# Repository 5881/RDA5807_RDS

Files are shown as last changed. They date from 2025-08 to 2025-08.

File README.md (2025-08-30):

# Радиоприёмник на RDA5807 с поддержкой RDS
Отображается название станций (блок 0A/0B), дата и время (блок 4A) и 
радиотекст (блок 2A). Использован микроконтроллер STM32F103C8T6 и TFT 
дисплей 128x128 на ST7735. Код написан на C с использованием библиотеки 
LibopenCM3. Отличается хорошей чувствительностью и очень приличным 
качеством звучания плюс кварцевая стабилизация.

# RDS-enabled RDA5807 radio
Shows the name of the stations (block 0A/0B), date and time (block 4A) 
and Radiotext (Block 2A). STM32F103C8T6 microcontroller and TFT 128x128 
display on ST7735 was used. The code is written in C using the 
LibopenCM3. It is characterized by good sensitivity and very decent 
sound quality plus quartz stabilization.

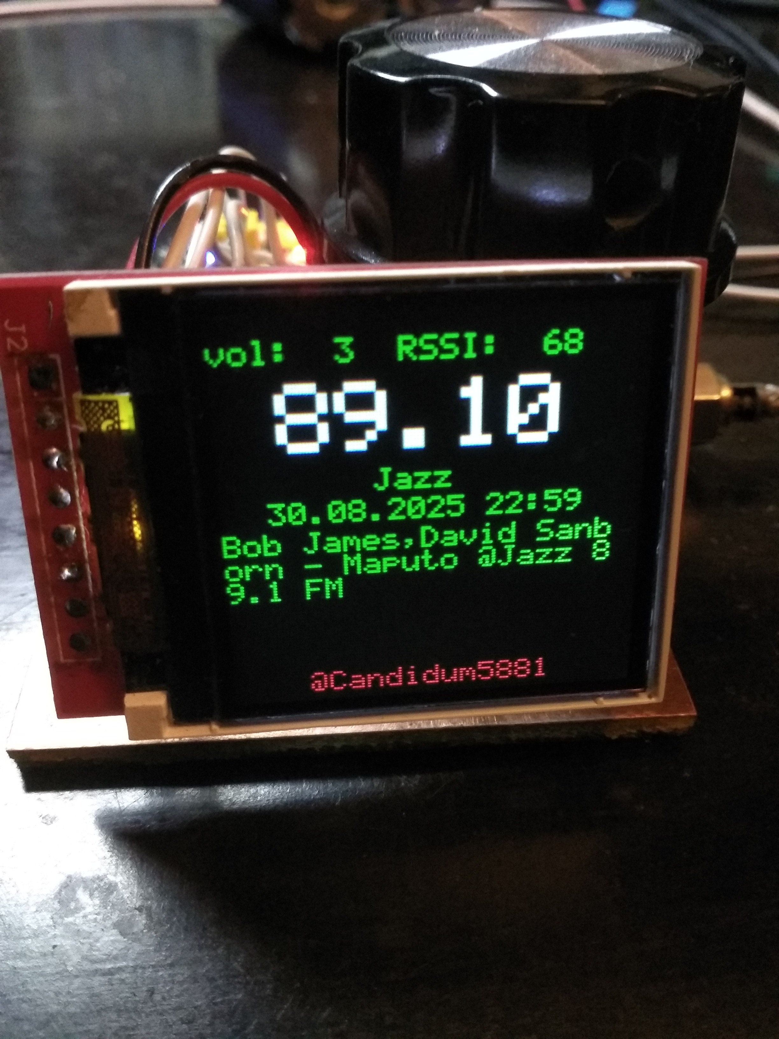
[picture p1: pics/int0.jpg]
Display


# Instructions
 
 1. $sudo pacman -S openocd arm-none-eabi-binutils arm-none-eabi-gcc arm-none-eabi-newlib arm-none-eabi-gdb
 2. $git clone https://github.com/5881/RDA5807_RDS.git
 3. $cd RDA5807_RDS
 4. $git submodule update --init # (Only needed once)
 5. $TARGETS=stm32/f1 make -C libopencm3 # (Only needed once)
 6. $make 
 7. $make flash

Александр Белый 2025

@candidum5881

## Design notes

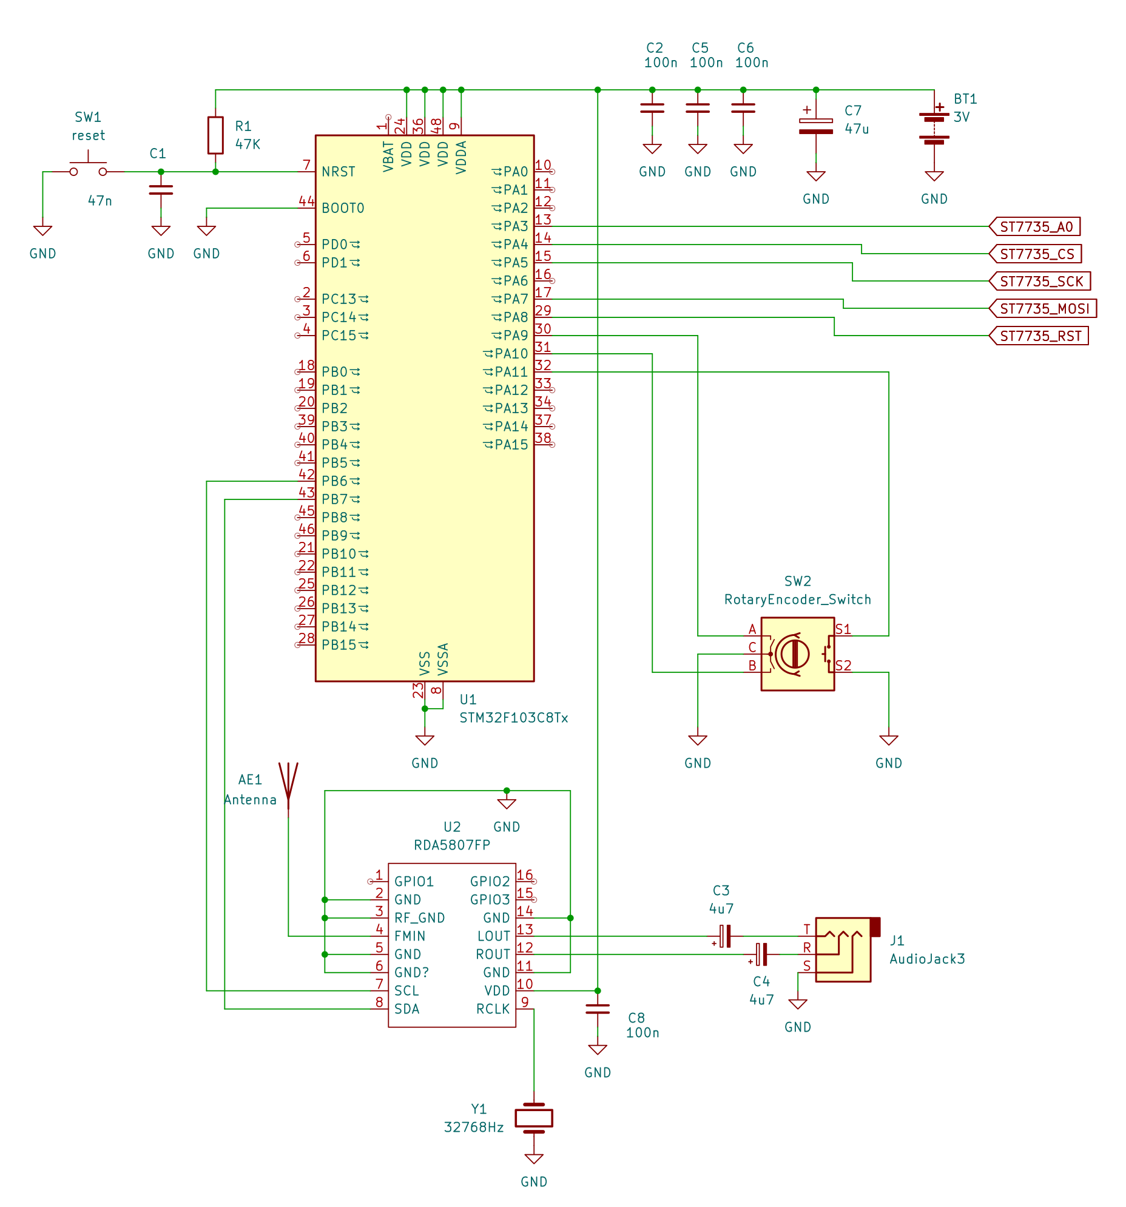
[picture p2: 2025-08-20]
schematic/rda5807.png

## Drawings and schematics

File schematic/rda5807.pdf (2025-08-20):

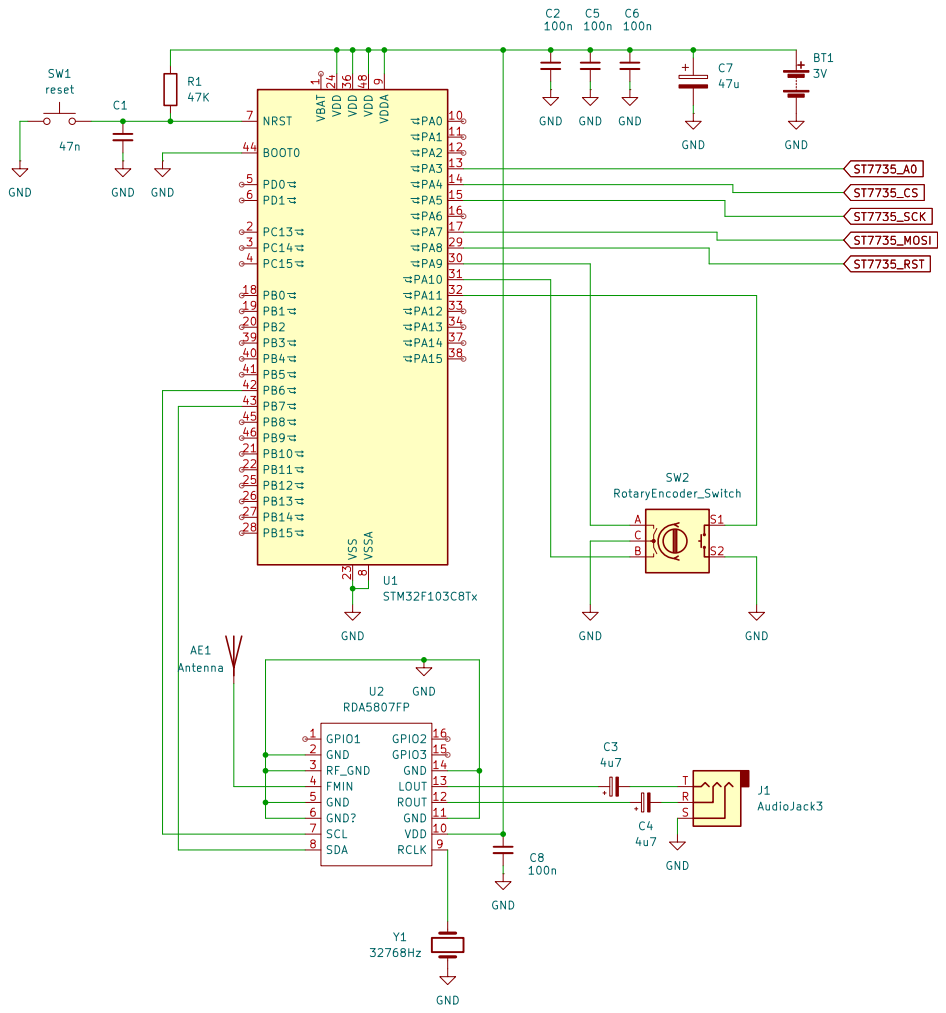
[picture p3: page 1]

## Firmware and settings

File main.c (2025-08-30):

/*
 * Приёмник RDA5807
 * v0.1 15 aug 2025
 * v0.9 20 aug 2025
 * v1.0 30 aug 2025
 * выкинул st_printf и заменил на stdio
 * Alexandr Belyy
 * /

/**********************************************************************
 * Секция include и defines
**********************************************************************/
#include <libopencm3/stm32/rcc.h>
//#include <libopencm3/stm32/timer.h>
#include <libopencm3/stm32/gpio.h>
//#include <libopencm3/stm32/adc.h>
#include <libopencm3/stm32/spi.h>
#include <libopencm3/stm32/exti.h>
#include <libopencm3/cm3/nvic.h>
#include "st7735_128x128.h"
#include "rda5807.h"
#include <libopencm3/stm32/i2c.h>
//#include "st_printf.h"
#include <stdio.h>
#include <string.h>
//#include "logo.h"

uint32_t freq=89100;
uint8_t vol=2;
uint8_t rssi;
uint8_t mode=1;

void change_setting(int cmd){
//static uint8_t encoder_mode=0;

/*mode
 * 1- freq
 * 0- vol
 *encoder mode
 * 0-change mode
 * 1-change set
 */
switch (cmd){
	case 1:
		if(mode) {if(freq<108000)freq+=100;} else {if(vol<15)vol+=1;}
		break;
	case -1:
		if(mode) {if(freq>76000)freq-=100;} else {if(vol>0)vol-=1;}
		break;
	case 0:
		mode=!mode;
		break;
	}
}

void applay_setting(){
	static uint32_t old_freq=87000;
	static uint8_t old_vol=0;
	if(freq!=old_freq){RDA5807_set_freq(freq); old_freq=freq;}
	if(vol!=old_vol){RDA5807_set_vol(vol); old_vol=vol;}
}

static void spi1_init(void){
	//spi1 - display
	/* Enable SPI1 Periph and gpio clocks */
	//rcc_periph_clock_enable(RCC_AFIO);
	rcc_periph_clock_enable(RCC_SPI1);
	rcc_periph_clock_enable(RCC_GPIOA);
	/* Configure GPIOs:
	 * SCK=PA5 
	 * DC=PA3
	 * MOSI=PA7 
	 * STCS PA4
	 * RST PA8
	 */
	gpio_set_mode(GPIOA, GPIO_MODE_OUTPUT_50_MHZ,
            GPIO_CNF_OUTPUT_ALTFN_PUSHPULL, GPIO5|GPIO7);
    gpio_set_mode(GPIOA, GPIO_MODE_OUTPUT_50_MHZ,
	              GPIO_CNF_OUTPUT_PUSHPULL, GPIO3|GPIO4|GPIO8);
	              
  /* Reset SPI, SPI_CR1 register cleared, SPI is disabled */
	//spi_reset(SPI1);
  /* Set up SPI in Master mode with:
   * Clock baud rate: 1/64 of peripheral clock frequency
   * Clock polarity: Idle High
   * Clock phase: Data valid on 2nd clock pulse
   * Data frame format: 8-bit
   * Frame format: MSB First
   */
	spi_init_master(SPI1, SPI_CR1_BAUDRATE_FPCLK_DIV_2, 
					SPI_CR1_CPOL_CLK_TO_0_WHEN_IDLE,
					SPI_CR1_CPHA_CLK_TRANSITION_1,
					SPI_CR1_DFF_8BIT, SPI_CR1_MSBFIRST);
	//spi_set_full_duplex_mode(SPI1);
  /*
   * Set NSS management to software.
   *
   * Note:
   * Setting nss high is very important, even if we are controlling 
   * the GPIO
   * ourselves this bit needs to be at least set to 1, otherwise the spi
   * peripheral will not send any data out.
   */
	spi_enable_software_slave_management(SPI1);
	spi_set_nss_high(SPI1);
  /* Enable SPI1 periph. */
	spi_enable(SPI1);
	gpio_set(GPIOA,GPIO4);
	}

static void i2c_init(void){
	/* Enable clocks for I2C2 and AFIO. */
	rcc_periph_clock_enable(RCC_GPIOB);
	rcc_periph_clock_enable(RCC_I2C1);
	rcc_periph_clock_enable(RCC_AFIO);
	/* Set alternate functions for the SCL and SDA pins of I2C2. */
	gpio_set_mode(GPIOB, GPIO_MODE_OUTPUT_50_MHZ,
		      GPIO_CNF_OUTPUT_ALTFN_OPENDRAIN,
		      GPIO_I2C1_SCL|GPIO_I2C1_SDA);
	gpio_set(GPIOB,GPIO_I2C1_SCL|GPIO_I2C1_SDA);
	//SDA PB7
	//SCL PB6
	/* Disable the I2C before changing any configuration. */
	i2c_peripheral_disable(I2C1);
	//36 is APB1 speed in MHz
	i2c_set_speed(I2C1,i2c_speed_fm_400k,24);
	i2c_peripheral_enable(I2C1);
	}


void button_init(){
	rcc_periph_clock_enable(RCC_GPIOA);
	gpio_set_mode(GPIOA, GPIO_MODE_INPUT, GPIO_CNF_INPUT_PULL_UPDOWN,
													GPIO12);
	gpio_set(GPIOA,GPIO12);  
}
void exti_setup(){
	rcc_periph_clock_enable(RCC_GPIOA);
	rcc_periph_clock_enable(RCC_AFIO);
	nvic_enable_irq(NVIC_EXTI9_5_IRQ);
	// Set GPIO0 (in GPIO port A) to 'input float'.
	
	//gpio_set_mode(GPIOA, GPIO_MODE_INPUT, GPIO_CNF_INPUT_FLOAT,
	//												GPIO9|GPIO10);
	//gpio_set(GPIOA,GPIO9);  
	
	gpio_set_mode(GPIOA, GPIO_MODE_INPUT, GPIO_CNF_INPUT_PULL_UPDOWN, GPIO9|GPIO10);
	//gpio_set(GPIOA,GPIO9|GPIO10); 
	// Configure the EXTI subsystem. 
	exti_select_source(EXTI9, GPIOA);
	exti_set_trigger(EXTI9, EXTI_TRIGGER_FALLING);
	exti_enable_request(EXTI9);
	}

void exti9_5_isr(void)
{
	//прерывание энкодера
	//for(uint32_t i=0; i<0xfff;i++) __asm__("nop");
	if(gpio_get(GPIOA,GPIO10)) change_setting(-1);
		else change_setting(1);
	gpio_toggle(GPIOB,GPIO12);
	for(uint32_t i=0; i<0xfff;i++) __asm__("nop");
	exti_reset_request(EXTI9);
}


void indicate(){
	char temp[50];
	uint8_t i;
	
	static uint32_t freq_old=100000;
	static uint8_t vol_old=1;
	static uint8_t rssi_old=30;
	static uint8_t stationname[9]="stationX";
	static uint8_t str64[65]={0};
	static uint32_t unixtime;
	
	//sprintf(temp,"All is OK!");
	//st7735_string_at(1,2,temp,GREEN,BLACK);
	
	if(vol!=vol_old){
	sprintf(temp,"vol: %2d",vol);
	st7735_string_at(1,10,temp,GREEN,BLACK);

	vol_old=vol;
	}
	
	rssi=RDA5807_get_rssi();
	if(rssi_old!=rssi){
	sprintf(temp,"RSSI: %3d",rssi);
	st7735_string_at(55,10,temp,GREEN,BLACK);
	rssi_old=rssi;
	}
	
	if(freq_old!=freq){
	uint16_t a,b;
	a=freq/1000;
	b=freq%1000/10;
	sprintf(temp,"%3d.%02d",a,b);
	st7735_string_x3_at(2,23,temp,WHITE,BLACK);
	freq_old=freq;
	}
	//Читаем и декодируем RDA
	uint8_t status=RDA5807_rds_decode(stationname,&unixtime,str64);
	//Название станции строка 8 символов
	if(status&1)st7735_string_at(35,50,stationname,GREEN,BLACK);
	//lfnf
	if(status&1<<1){
		//sprintf(temp,"%10d    ",unixtime);
		//st7735_string_at(1,70,temp,GREEN,BLACK);
		uint16_t year;
		uint8_t month,day,hours,minutes;
		RDA5807_unixtime_to_datetime(unixtime,&year,&month,&day,&hours,&minutes);
		sprintf(temp,"%02d.%02d.%04d %02d:%02d    ",day,month,year,hours,minutes);
		st7735_string_at(15,60,temp,GREEN,BLACK);
	}
	//Радиотекст строка 64 символа.
	if(status&1<<2){
		uint8_t clear_flag=0;
		for(uint8_t i=0;i<64;i++){
			if(str64[i]==0x0D)clear_flag=1;
			if(clear_flag)str64[i]=0x20;
			}
		strncpy(temp,str64,20);
		temp[20]=0;
		st7735_string_at(1,70,temp,GREEN,BLACK);
		strncpy(temp,str64+20,20);
		temp[20]=0;
		st7735_string_at(1,78,temp,GREEN,BLACK);
		strncpy(temp,str64+40,20);
		temp[20]=0;
		st7735_string_at(1,86,temp,GREEN,BLACK);
		strncpy(temp,str64+60,20);
		temp[20]=0;
		st7735_string_at(1,94,temp,GREEN,BLACK);
		//stprintf(str64);
	}
	//sprintf(temp,"Alexander Belyy 2025");
	//st7735_string_at(1,110,temp,GREEN,BLACK);
	//sprintf(temp,"@Candidum5881");
	//st7735_string_at(25,120,temp,RED,BLACK);
	
}

void led_init(void){
	rcc_periph_clock_enable(RCC_GPIOB);
	gpio_set_mode(GPIOB, GPIO_MODE_OUTPUT_50_MHZ,
	              GPIO_CNF_OUTPUT_PUSHPULL, GPIO12);
	gpio_clear(GPIOB,GPIO12);
}

void main(){
	char temp[50];
	for(uint32_t i=0; i<0xffff;i++) __asm__("nop");
	//rcc_clock_setup_in_hse_8mhz_out_72mhz();
	rcc_clock_setup_in_hse_8mhz_out_24mhz();
	led_init();
	spi1_init();
	i2c_init();
	st7735_init();
	exti_setup();
	st7735_clear(BLACK);
	st7735_set_printf_color(GREEN,BLACK);
	//stprintf("Display is OK!\n");
	RDA5807_init();
	//stprintf("\a");
	sprintf(temp,"@Candidum5881");
	st7735_string_at(25,120,temp,RED,BLACK);
	while (1){
			for(uint32_t i=0; i<0xffff;i++) __asm__("nop");
			gpio_toggle(GPIOB,GPIO12);
			applay_setting();
			indicate();
			if(!gpio_get(GPIOA,GPIO12)){
				while(!gpio_get(GPIOA,GPIO12))__asm__("nop");
			//	gpio_toggle(GPIOB,GPIO12);
				change_setting(0);
				}
			}
	
}

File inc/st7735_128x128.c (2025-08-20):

/*Библиотека для работы с tft дисплеем 128x128 st7735
 * v 0.9
 * использована libopencm3
 * 16 mar 2019
 * Alexander Belyy
 * 
 * v0.91
 * добавлено масштабирование текста х2
 * v0.92
 * добавлен вывод побайтно как в терминале 12 мая 2019
 * v0.93
 * добавлена поддержка backspase \b 27 июля 2019
 * v0.94
 * Привёл к пристойному виду. 28 июля 2019
 */
#include <stdint.h>
#include <string.h>
#include <libopencm3/stm32/gpio.h>
#include <libopencm3/stm32/spi.h>
#include "st7735_128x128.h"

#define OFFSETX 1
#define OFFSETY 2
/*********************************************************************
 * Секция переменных
 *********************************************************************/
uint16_t pos=0;
static uint16_t txt_color=GREEN;
static uint16_t bg_color=BLACK;

static const char ASCII[][5] =
{
 {0x00, 0x00, 0x00, 0x00, 0x00} // 20  
,{0x00, 0x00, 0x5f, 0x00, 0x00} // 21 !
,{0x00, 0x07, 0x00, 0x07, 0x00} // 22 "
,{0x14, 0x7f, 0x14, 0x7f, 0x14} // 23 #
,{0x24, 0x2a, 0x7f, 0x2a, 0x12} // 24 $
,{0x23, 0x13, 0x08, 0x64, 0x62} // 25 %
,{0x36, 0x49, 0x55, 0x22, 0x50} // 26 &
,{0x00, 0x05, 0x03, 0x00, 0x00} // 27 '
,{0x00, 0x1c, 0x22, 0x41, 0x00} // 28 (
,{0x00, 0x41, 0x22, 0x1c, 0x00} // 29 )
,{0x14, 0x08, 0x3e, 0x08, 0x14} // 2a *
,{0x08, 0x08, 0x3e, 0x08, 0x08} // 2b +
,{0x00, 0x50, 0x30, 0x00, 0x00} // 2c ,
,{0x08, 0x08, 0x08, 0x08, 0x08} // 2d -
,{0x00, 0x60, 0x60, 0x00, 0x00} // 2e .
,{0x20, 0x10, 0x08, 0x04, 0x02} // 2f /
,{0x3e, 0x51, 0x49, 0x45, 0x3e} // 30 0
,{0x00, 0x42, 0x7f, 0x40, 0x00} // 31 1
,{0x42, 0x61, 0x51, 0x49, 0x46} // 32 2
,{0x21, 0x41, 0x45, 0x4b, 0x31} // 33 3
,{0x18, 0x14, 0x12, 0x7f, 0x10} // 34 4
,{0x27, 0x45, 0x45, 0x45, 0x39} // 35 5
,{0x3c, 0x4a, 0x49, 0x49, 0x30} // 36 6
,{0x01, 0x71, 0x09, 0x05, 0x03} // 37 7
,{0x36, 0x49, 0x49, 0x49, 0x36} // 38 8
,{0x06, 0x49, 0x49, 0x29, 0x1e} // 39 9
,{0x00, 0x36, 0x36, 0x00, 0x00} // 3a :
,{0x00, 0x56, 0x36, 0x00, 0x00} // 3b ;
,{0x08, 0x14, 0x22, 0x41, 0x00} // 3c <
,{0x14, 0x14, 0x14, 0x14, 0x14} // 3d =
,{0x00, 0x41, 0x22, 0x14, 0x08} // 3e >
,{0x02, 0x01, 0x51, 0x09, 0x06} // 3f ?
,{0x32, 0x49, 0x79, 0x41, 0x3e} // 40 @
,{0x7e, 0x11, 0x11, 0x11, 0x7e} // 41 A
,{0x7f, 0x49, 0x49, 0x49, 0x36} // 42 B
,{0x3e, 0x41, 0x41, 0x41, 0x22} // 43 C
,{0x7f, 0x41, 0x41, 0x22, 0x1c} // 44 D
,{0x7f, 0x49, 0x49, 0x49, 0x41} // 45 E
,{0x7f, 0x09, 0x09, 0x09, 0x01} // 46 F
,{0x3e, 0x41, 0x49, 0x49, 0x7a} // 47 G
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
};

 
 
 
 
 /********************************************************************
  * Секция основных функций
  ********************************************************************/
void st7735_set_printf_color(uint16_t textcolor, uint16_t bgcolor){
	txt_color=textcolor;
	bg_color=bgcolor;	
}


void st7735_sendcmd(unsigned char cmd){
	gpio_clear(STPORT, DC);
	spi_send(SPI,cmd);
	while (SPI_SR(SPI) & SPI_SR_BSY);
	}
void st7735_senddata(unsigned char data){
	gpio_set(STPORT, DC);
	spi_send(SPI,data);
	while (SPI_SR(SPI) & SPI_SR_BSY);
	}

void st7735_init(void){
	uint32_t i;
	
	//for(i=0;i<0xfff;i++)__asm__("nop");
	gpio_set(STPORT,RST);
	gpio_clear(STPORT,STCS);
	for(i=0;i<0xfff;i++)__asm__("nop");
	gpio_clear(STPORT,RST);
	for(i=0;i<0xfff;i++)__asm__("nop");
	gpio_set(STPORT,RST);
	for(i=0;i<0xfff;i++)__asm__("nop");
	
	st7735_sendcmd(ST7735_SWRESET);//0x01
	for(i=0;i<0x5fff;i++)__asm__("nop");
	
	st7735_sendcmd(ST7735_SLPOUT);//0x11
	for(i=0;i<0x5fff;i++)__asm__("nop");
	
	st7735_sendcmd(ST7735_COLMOD);
	st7735_senddata(0x5);
	//st7735_sendcmd(0x26);
	//st7735_senddata(0x2);
	
	st7735_sendcmd(ST7735_FRMCTR1);
	st7735_senddata(0x00);
	st7735_senddata(0x06);
	st7735_senddata(0x03);
	//Вот эта поебен отвечает за ориентацию дисплея
	//даташит стр 54
	st7735_sendcmd(ST7735_MADCTL);
#ifdef HORIZONTAL
	st7735_senddata(MV|MX|RGB); //mv set def is 0
	//st7735_senddata(MV|MY|RGB); //mv set def is 0
#else
	st7735_senddata(0x0);
#endif
	//st7735_sendcmd(ST7735_DISSET5);
	//st7735_senddata(0x15);
	//st7735_senddata(0x02);

	
	
	st7735_sendcmd(ST7735_CASET);
	st7735_senddata(0x00);
	st7735_senddata(0x00);
	st7735_senddata(0x00);
	//st7735_senddata(0x00);
	st7735_senddata(0xa4);

	st7735_sendcmd(ST7735_RASET);
	st7735_senddata(0x00);
	//st7735_senddata(0xa4);
	st7735_senddata(0x00);
	st7735_senddata(0x00);
	st7735_senddata(0xa4);

	
	
	st7735_sendcmd(ST7735_NORON);
	for(i=0;i<0xfff;i++)__asm__("nop");
	
	st7735_sendcmd(ST7735_DISPON);
	for(i=0;i<0xfff;i++)__asm__("nop");
	
		
	while (SPI_SR(SPI) & SPI_SR_BSY);
	gpio_set(STPORT,STCS);
}

void st7735_wake(void){
	//st7735_init();
	gpio_clear(STPORT,STCS);
	st7735_sendcmd(ST7735_DISPON);
	gpio_set(STPORT,STCS);
	gpio_set(GPIOB,GPIO0);
	}

void st7735_sleep(void){
	gpio_clear(STPORT,STCS);
	st7735_sendcmd(ST7735_DISPOFF);
	gpio_set(STPORT,STCS);
	gpio_clear(GPIOB,GPIO0);
	}

void st7735_addrset(unsigned char sx,unsigned char sy,
								unsigned char ex,unsigned char ey){
	st7735_sendcmd(ST7735_CASET); // Column address set 2a
	gpio_set(GPIOA,DC);
	spi_send(SPI,0x00);
	spi_send(SPI,sx);
	spi_send(SPI,0x00);
	spi_send(SPI,ex);

	while (SPI_SR(SPI) & SPI_SR_BSY);

	st7735_sendcmd(ST7735_RASET);   // Row address set 2b
	gpio_set(GPIOA,DC);
	spi_send(SPI,0x00);
	spi_send(SPI,sy);
	spi_send(SPI,0x00);
	spi_send(SPI,ey);
	
	while (SPI_SR(SPI) & SPI_SR_BSY);
	st7735_sendcmd(ST7735_RAMWR);   // Memory write			
	}

void st7735_clear(uint16_t color){
	unsigned char BCH,BCL;
	BCL = color & 0xFF;
	BCH = color>>8;
	gpio_clear(STPORT,STCS);
	//for(uint8_t i=0;i<0xff;i++)__asm__("nop");

#ifdef HORIZONTAL
	st7735_addrset(0,2,128,132);
#else
	st7735_addrset(0,0,128,132);
#endif
	gpio_set(STPORT,DC);
	for(uint16_t i=0;i<128*132;i++){
		spi_send(SPI,BCH);
		spi_send(SPI,BCL);
		}
	while (SPI_SR(SPI) & SPI_SR_BSY);
	gpio_set(STPORT,STCS);
	}

//debug func

void st7735_draw_s_char(unsigned char x,unsigned char y,char chr,
								uint16_t color, uint16_t bg_color){
									
	unsigned char i,j;
	unsigned char CH,CL,BCH,BCL;
	unsigned char buffer[6];
	CL = color & 0xFF;
	CH = color>>8;
	BCL = bg_color & 0xFF;
	BCH = bg_color>>8;
	
	memcpy(buffer,&ASCII[chr-0x20],5);
	buffer[5]=0;
	
	gpio_clear(STPORT,STCS);
	st7735_addrset(x,y,x+5,y+7);
	gpio_set(GPIOA,DC);
	for(unsigned char i=0;i<8;i++){
		for(unsigned char j=0;j<6;j++){
			if((buffer[j] & (1<<i))){
				spi_send(SPI,CH);
				spi_send(SPI,CL);
				}
				else{
				spi_send(SPI,BCH);
				spi_send(SPI,BCL);
				}
			}
		}
	
	while (SPI_SR(SPI) & SPI_SR_BSY);
	gpio_set(STPORT,STCS);

}

//end debug func
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

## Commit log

2025-08-20 ver 0.9
    [rda5807fp.kicad_sch]
2025-08-21 spi init fix
2025-08-30 debug led PB12
